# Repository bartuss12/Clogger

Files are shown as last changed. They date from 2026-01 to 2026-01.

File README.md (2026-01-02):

Clogger — Minimal Linux‑Powered USB eMMC Reader (F1C100S)
Clogger is a tiny, reproducible hardware project built around the Allwinner F1C100S, 
designed to read, clone, and analyze BGA153/BGA169 eMMC chips using nothing more than a Linux system running from an SD card. 
The goal is to create a fully open, hand‑solderable tool that exposes an attached eMMC device to a host PC over USB 
— just like a USB mass‑storage adapter, but built from scratch.

🔧 Goals

*Build a minimal F1C100S board that boots Linux entirely from an SD card

*Provide a UART‑accessible Linux shell for debugging and control

*Use USB gadget mode to expose the connected eMMC as a block device

*Support BGA153/BGA169 eMMC reballing using low‑cost stencils and solder paste

*Offer a fully reproducible Buildroot toolchain (U‑Boot + kernel + rootfs)

*Document the entire bring‑up process: boot flow, device tree, SD layout, and USB configuration

*Create a simple, reliable tool for eMMC backup, cloning, and recovery

29.12.2025 Work on first hardware version started


31.12.2025 Added 3D models, added LEDs (for work without terminal), added decoupling capacitors, added line resistors


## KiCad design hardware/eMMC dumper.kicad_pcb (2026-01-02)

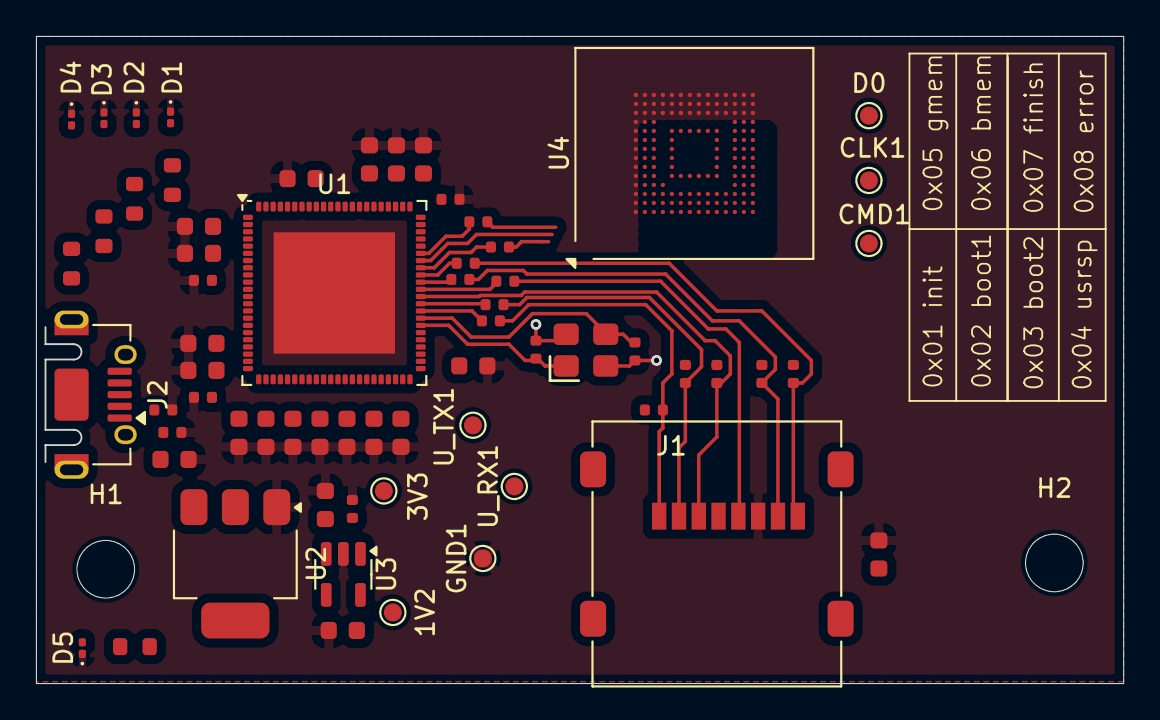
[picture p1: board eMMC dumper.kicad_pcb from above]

Board: 2 copper layers, 60.4 x 36.0 mm, 67 parts (0 on the bottom side), 39 nets.

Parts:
1V2, 3V3: TestPoint; TestPoint_Pad_D1.0mm
C1, C2, C3, C7, C9, C10, C11, C12, C13, C14, C15, C16, C18, C19, C20, C21, C22, C23, C24, C26: 100nF; C_0603
C4, C5, C6, C8, C17, C25: 1uF; C_0402
C27, C28: 18pF; C_0402
CLK1: TestPoint; TestPoint_Pad_D1.0mm
CMD1: TestPoint; TestPoint_Pad_D1.0mm
D0: TestPoint; TestPoint_Pad_D1.0mm
D1, D2, D3, D4, D5: LED; LED_0201_0603Metric
GND1: TestPoint; TestPoint_Pad_D1.0mm
H1, H2: MountingHole; MountingHole_3.2mm_M3
J1: Micro_SD_Card; microSD_HC_Molex_47219-2001
J2: USB_B_Micro; USB_Micro-AB_Molex_47590-0001
R1, R2, R3, R4, R5, R6, R7: 33Ω; R_0402
R8, R9, R10, R11, R12: 47kΩ; R_0402
R13, R14, R15, R16, R17: 1kΩ; R_0603
U1: F1C100s; ArtInChip_QFN-88-1EP_10x10mm_P0.4mm_EP6.74x6.74mm
U2: AMS1117-3.3; SOT-223-3_TabPin2
U3: TLV75512PDBV (WL9193S5-12); SOT-23-5
U4: EMMC04G-M627-A01; LFBGA-153_11.5x13mm_Layout14x14_P0.5mm
U_RX1: TestPoint; TestPoint_Pad_D1.0mm
U_TX1: TestPoint; TestPoint_Pad_D1.0mm
X1: 24MHz; OSC-SMD_4P-L3.2-W2.5-BL

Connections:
+1V2: 1V2.1, C3.1, C7.1, C8.1, C9.1, C10.1, U1.22 (VDD_CORE), U1.35 (VDD_CORE), U1.71 (VDD_CORE), U3.5 (OUT)
+3V3: 3V3.1, C2.1, C6.1, C11.1, C12.1, C13.1, C14.1, C15.1, C16.1, C17.1, C18.1, C19.1, C20.1, C21.1, C22.1, C23.1, C24.1, C25.1, C26.1, J1.4 (VDD), R8.1, R9.1, R10.1, R11.1, R12.1, R17.2, U1.4 (HPVCC), U1.5 (VCC_IO), U1.20 (VCC_IO), U1.30 (VCC_DRAM), U1.31 (VCC_DRAM), U1.32 (VCC_DRAM), U1.33 (SVREF), U1.34 (VCC_DRAM), U1.36 (VCC_DRAM), U1.50 (VCC_IO), U1.67 (UVCC), U1.73 (TV_VCC), U1.80 (AVCC), U2.2 (VO), U3.1 (IN), U3.3 (EN)
/Linux_core/CLK: J1.5 (CLK), R5.2
/Linux_core/CLK_eMMC: CLK1.1, R1.1, U4.M6 (CLK)
/Linux_core/CMD: J1.3 (CMD), R10.2, U1.55 (PF3/SDC0_CMD/DBG_DO/EINTF3)
/Linux_core/CMD_eMMC: CMD1.1, U1.60 (PC1/SPI0_CS/SDC1_CMD), U4.M5 (CMD)
/Linux_core/D0: J1.7 (DAT0), R4.2, R11.2
/Linux_core/D0_eMMC: D0.1, R2.1, U4.A3 (DAT0)
/Linux_core/D1: J1.8 (DAT1), R3.2, R12.2
/Linux_core/D2: J1.1 (DAT2), R7.2, R8.2
/Linux_core/D3: J1.2 (DAT3/CD), R6.2, R9.2
/Linux_core/LED_1: D1.2 (A), R13.1
/Linux_core/LED_2: D2.2 (A), R14.1
/Linux_core/LED_3: D3.2 (A), R15.1
/Linux_core/LED_4: D4.2 (A), R16.1
/Linux_core/UART-TX: U1.48 (PE1/CSI_VSYNC/LCD_D1/TWI2_SDA/UART0_TX/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), U_TX1.1
/Linux_core/UART_RX: U1.49 (PE0/CSI_HSYNC/LCD_D0/TWI2_SCK/UART0_RX/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), U_RX1.1
/Linux_core/USB_DM: J2.2 (D-), U1.68 (USB-DM)
/Linux_core/USB_DP: J2.3 (D+), U1.69 (USB-DP)
/Power/V_IN: C1.1, C4.1, C5.1, J2.1 (VBUS), U2.3 (VI)
GND: C1.2, C2.2, C3.2, C4.2, C5.2, C6.2, C7.2, C8.2, C9.2, C10.2, C11.2, C12.2, C13.2, C14.2, C15.2, C16.2, C17.2, C18.2, C19.2, C20.2, C21.2, C22.2, C23.2, C24.2, C25.2, C26.2, C27.2, C28.2, D1.1 (K), D2.1 (K), D3.1 (K), D4.1 (K), D5.1 (K), GND1.1, J1.6 (VSS), J2.5 (GND), U1.74 (TVGND), U1.82 (AGND), U1.89 (EPAD), U2.1 (GND), U3.2 (GND), X1.2 (GND), X1.4 (GND)
unnamed: D5.2 (A), R17.1
unnamed: C27.1, U1.51 (HOSCI), X1.1 (OSC)
unnamed: C28.1, U1.52 (HOSCO), X1.3 (OSC)
unnamed: R1.2, U1.59 (PC0/SPI0_CLK/SDC1_CLK)
unnamed: R2.2, U1.61 (PC2/SPI0_MISO/SDC1_D0)
unnamed: R13.2, U1.6 (PD0/LCD_D2/TWI0_SDA/RSB_SDA/EINTD0)
unnamed: R14.2, U1.7 (PD1/LCD_D3/UART1_RTS/EINTD1)
unnamed: R15.2, U1.8 (PD2/LCD_D4/UART1_CTS/EINTD2)
unnamed: R16.2, U1.9 (PD3/LCD_D5/UART1_RX/EINTD3)
unnamed: R3.1, U1.58 (PF0/SDC0_D1/DBG_MS/IR_RX/EINTF0)
unnamed: R4.1, U1.57 (PF1/SDC0_D0/DBG_DI/EINTF1)
unnamed: R5.1, U1.56 (PF2/SDC0_CLK/UART0_RX/EINTF2)
unnamed: R6.1, U1.54 (PF4/SDC0_D3/UART0_TX/EINTF4)
unnamed: R7.1, U1.53 (PF5/SDC0_D2/DBG_CK/PWM1/EINTF5)
VCC: U4.E6 (VCC), U4.F5 (VCC), U4.J10 (VCC), U4.K9 (VCC)
VCCQ: U4.C6 (VCCQ), U4.M4 (VCCQ), U4.N4 (VCCQ), U4.P3 (VCCQ), U4.P5 (VCCQ)
VSS: U4.A6 (VSS), U4.E7 (VSS), U4.G5 (VSS), U4.H10 (VSS), U4.J5 (VSS), U4.K8 (VSS)
VSSQ: U4.C4 (VSSQ), U4.N2 (VSSQ), U4.N5 (VSSQ), U4.P4 (VSSQ), U4.P6 (VSSQ)

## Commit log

2017-01-02 First version of code
    -reading signals after button is pushed
    -sending signal after other button is pushed
2025-12-29 Added hw project
    [eMMC dumper.kicad_pcb, eMMC dumper.kicad_sch, untitled.kicad_sch]
2025-12-29 Basic schematic
    Need to add passives
    [eMMC dumper.kicad_sch, power.kicad_sch, untitled.kicad_sch]
2025-12-29 added data/clk resistors (33ohm)
    [eMMC dumper.kicad_sch, power.kicad_sch, untitled.kicad_sch]
2025-12-29 Added core decoupling caps
    [eMMC dumper.kicad_sch, power.kicad_sch, untitled.kicad_sch]
2025-12-29 Added pullups for SD card
    [eMMC dumper.kicad_sch, power.kicad_sch]
2025-12-29 Board design started
    [eMMC dumper.kicad_pcb, eMMC dumper.kicad_sch, power.kicad_sch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]
2025-12-30 Started placing decoupling capacitors
    [eMMC dumper.kicad_pcb, eMMC dumper.kicad_sch]
2025-12-31 PCB major changes
    [eMMC dumper.kicad_pcb, eMMC dumper.kicad_sch, untitled.kicad_sch]
2026-01-02 Moved LEDs, renamed testpoints
    [eMMC dumper.kicad_pcb, eMMC dumper.kicad_sch, untitled.kicad_sch]
2026-01-02 added quartz
    [untitled.kicad_sch]
2026-01-02 Moved some parts, started routing
    [eMMC dumper.kicad_pcb]
